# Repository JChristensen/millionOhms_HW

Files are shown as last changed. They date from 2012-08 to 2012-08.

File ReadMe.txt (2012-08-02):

Million Ohms Project Hardware
Jack Christensen
V1.2 31Jul2012

This repository contains the following for the Million Ohms project:

Assembly Instructions
Schematic
Eagle Files

This work is licensed under the Creative Commons Attribution-ShareAlike 3.0
Unported License. To view a copy of this license, visit
http://creativecommons.org/licenses/by-sa/3.0/ or send a letter to Creative
Commons, 171 Second Street, Suite 300, San Francisco, California, 94105, USA.

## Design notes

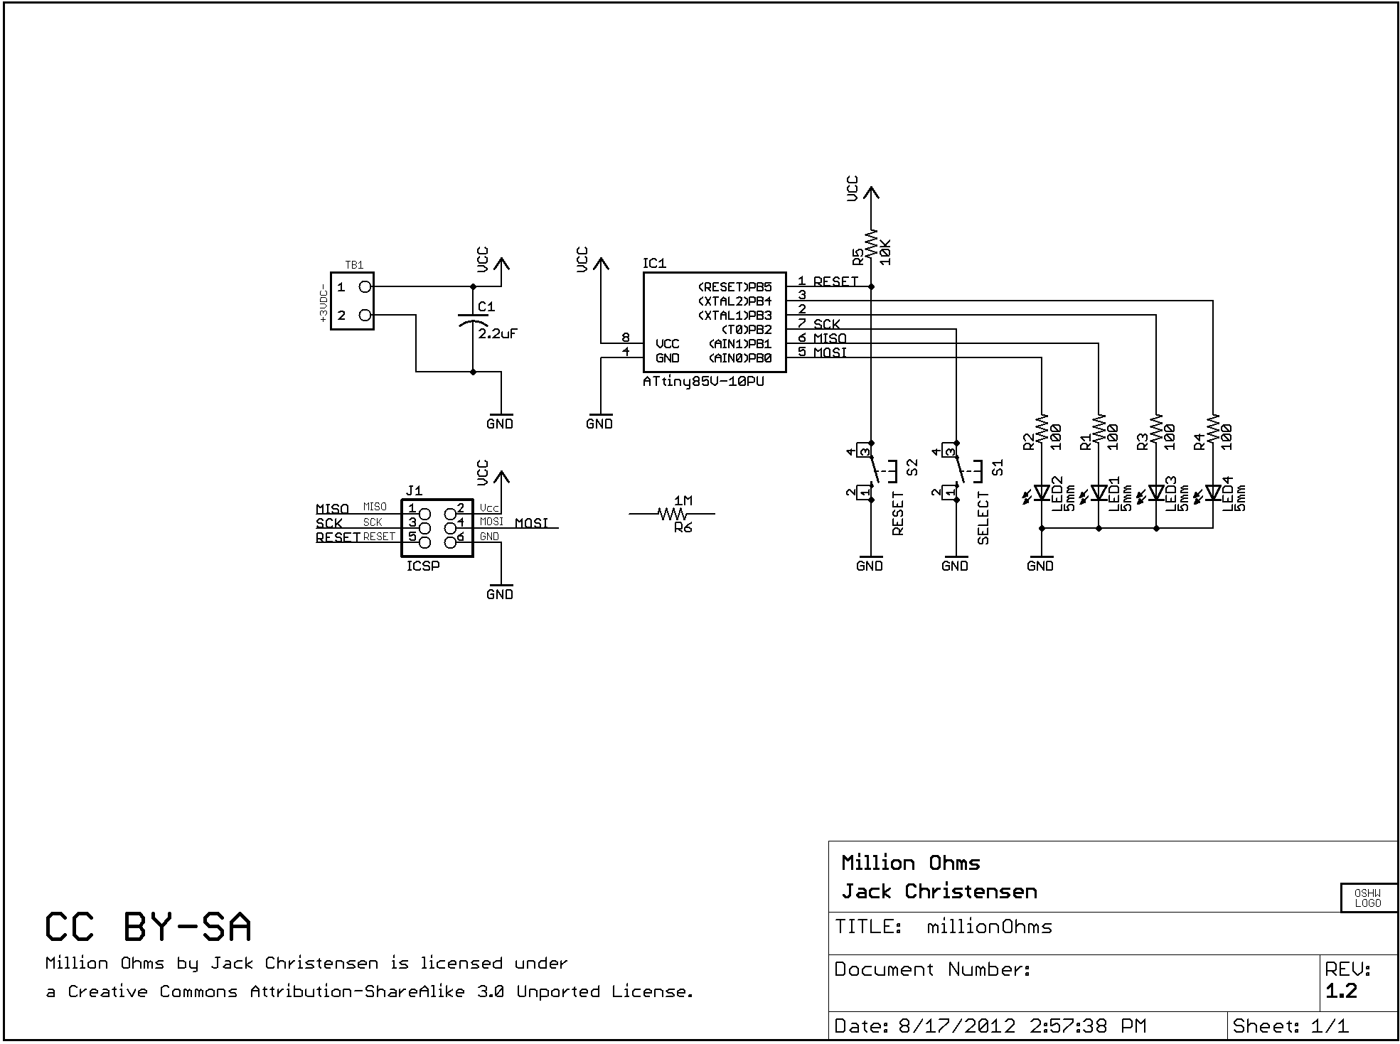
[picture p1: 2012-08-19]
schematic.png

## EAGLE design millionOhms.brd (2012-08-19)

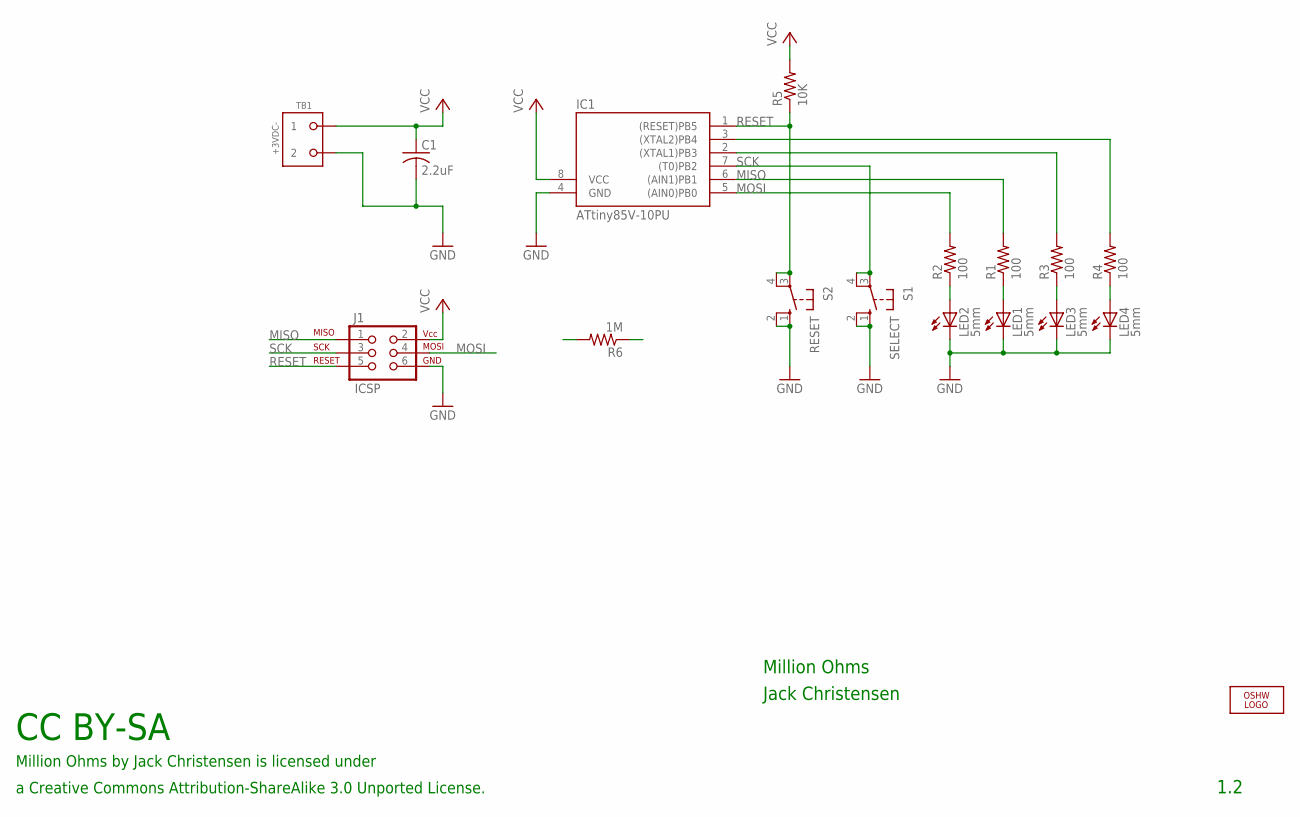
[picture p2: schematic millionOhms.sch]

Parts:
C1: 2.2uF; C025-025X050
IC1: ATtiny85V-10PU; DIL08
J1: ICSP; 2X3
LED1, LED2, LED3, LED4: 5mm; LED5MM
LOGO2: OSHW_LOGO_8MILX0150-NT; OSHW_8X150_NOTEXT
R1, R2, R3, R4: 100; 0204/6
R5: 10K; 0204/6
R6: 1M; 5616/20
S1: SELECT; B3F-10XXOCT
S2: RESET; B3F-10XXOCT
TB1: +3VDC-; OST-TB-2-3.5MM

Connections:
GND: C1.2, IC1.4 (GND), J1.6, LED1.K (C), LED2.K (C), LED3.K (C), LED4.K (C), S1.1 (S), S1.2 (S1), S2.1 (S), S2.2 (S1), TB1.P$2 (2)
MISO: IC1.6 ((AIN1)PB1), J1.1, R1.2
MOSI: IC1.5 ((AIN0)PB0), J1.4, R2.2
unnamed: LED2.A, R2.1
unnamed: LED1.A, R1.1
unnamed: LED3.A, R3.1
unnamed: LED4.A, R4.1
unnamed: IC1.2 ((XTAL1)PB3), R3.2
unnamed: IC1.3 ((XTAL2)PB4), R4.2
RESET: IC1.1 ((RESET)PB5), J1.5, R5.1, S2.3, S2.4 (P1)
SCK: IC1.7 ((T0)PB2), J1.3, S1.3, S1.4 (P1)
VCC: C1.1, IC1.8 (VCC), J1.2, R5.2, TB1.P$1 (1)

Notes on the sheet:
Million Ohms by Jack Christensen is licensed under
CC BY-SA
a Creative Commons Attribution-ShareAlike 3.0 Unported License.
Million Ohms
Jack Christensen
1.2

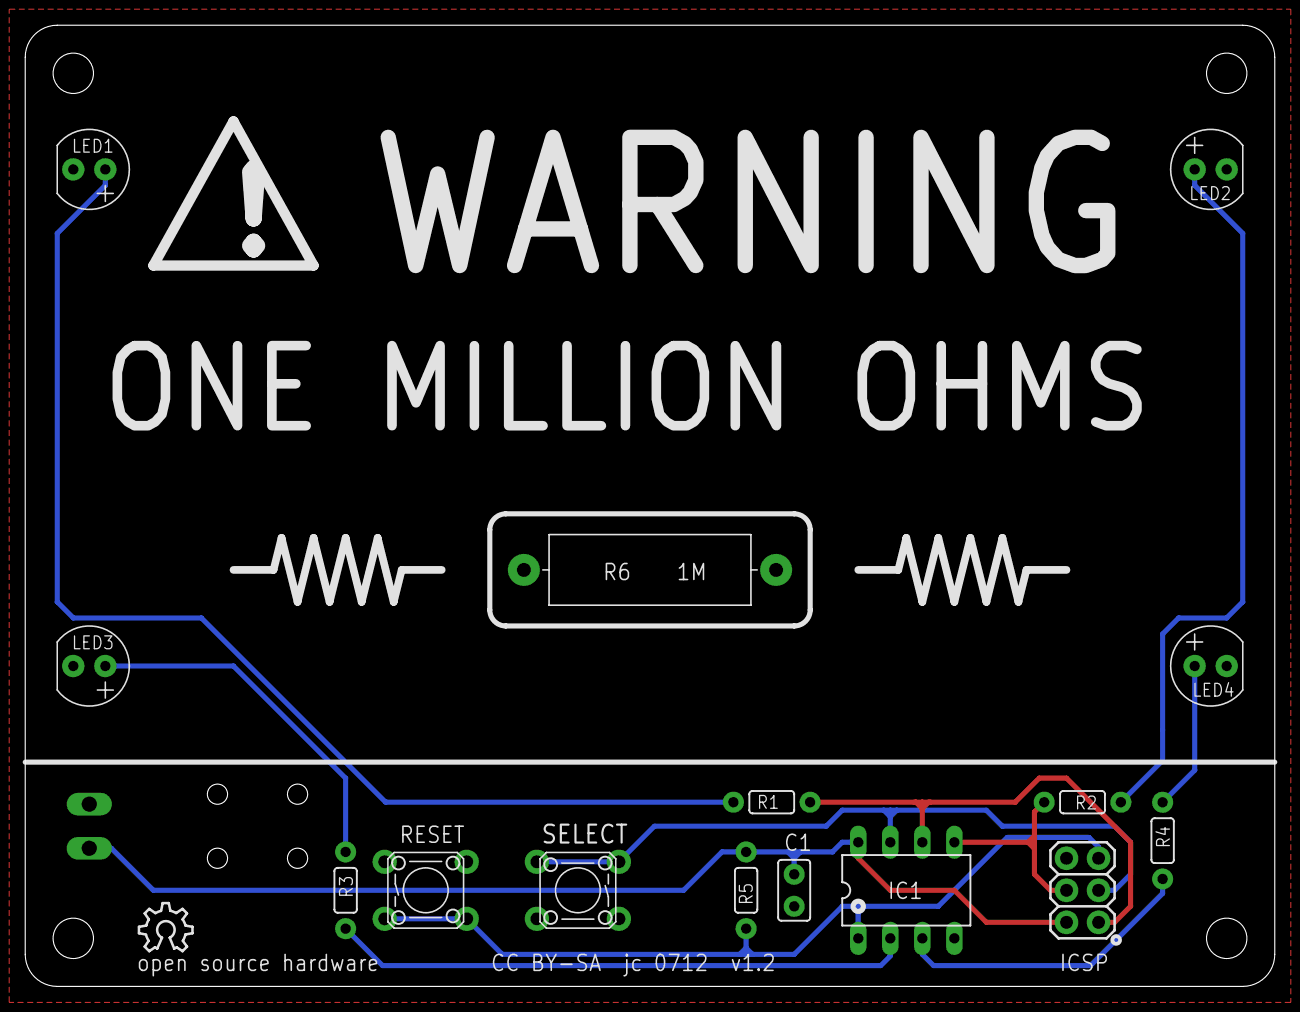
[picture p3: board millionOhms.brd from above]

Board: 2 copper layers, 99.1 x 76.2 mm, 17 parts (1 on the bottom side), 12 nets.

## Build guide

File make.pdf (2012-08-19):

## "One Million Ohms" Microcontroller Project Kit

Where to buy it: tinyurl.com/BuyMohms

Amuse your friends and confuse your enemies! Keep the uninitiated away from your workbench or desk and out of your lab!

- Great conversation piece or gag gift
- Big, scary 1,000,000 Ω resistor in the middle of the board
- Pre-programmed AVR microcontroller (ATtiny85)
- Arduino-compatible, hackable open-source hardware and software
- Can be re-programmed with an ICSP programmer, using either the Arduino (http://arduino.cc/) integrated development environment or WinAVR. (http://winavr.sourceforge.net/)

This soldering kit is an electronic version of an old joke known to physicists and engineers. Pressing the SELECT button turns the circuit on and causes the red LEDs to flash. To change the flashing speed and pattern, press SELECT again. Hold SELECT down to turn the circuit off, or it will automatically turn itself off after five minutes.

### Assembly Tips

1. Even though this is a simple kit that a beginner should be able to complete with little difficulty, these instructions are general in nature and assume that you know how to solder and can determine where to place the components on the board. If you need to learn how to solder, there are several good tutorials on the web. Check out SparkFun Electronics’ tutorial (tinyurl.com/3f4dpxj), and Adafruit Industries also has several good links (tinyurl.com/3ooo2fj).
2. Be sure to observe polarity when installing the following components. Observe the outlines on the board (also see Parts Placement on the last page of these instructions.)
a. LEDs may have a longer lead denoting positive (+) and/or a flat on the side denoting negative (-). See picture at tinyurl.com/d2bwtec
b. The microcontroller may have a notch on one end, and/or a small dot near pin 1.
c. Connect the red wire (positive) from the battery holder to the terminal block screw nearest the bottom of the board (+) and the black wire (negative) to the (-) screw. Observe polarity when installing batteries as marked on the battery holder.
3. The microcontroller is sensitive to static electricity and is shipped in conductive foam for protection. Normally a lot of fancy precautions aren’t necessary, but don’t scuff across the carpet and then touch the chip. Touch some metal object or appliance before handling the chip. Once soldered onto the board, the chip is safe.
4. As shipped from the factory, the leads on the microcontroller are spread out a bit and need to be bent in to fit into the board. One way to do this is to carefully press each side of the chip against a table top. Bend the four pins on each side just a bit so that they are parallel. See picture at tinyurl.com/9dahxr5

Where to buy it: tinyurl.com/BuyMohms

5. Double check the small resistors before soldering them. There is one 10,000 Ω (10 KΩ) resistor and four 100 Ω resistors. They only differ by one color-code band (see parts list below). If unsure, use a magnifying glass or an ohmmeter to check the values.
6. Positioning of the terminal block and battery holder is flexible depending on your intended use and installation of the board. To allow the board to stand at a slight angle on a desk, etc., put the terminal block and the battery holder on the back side of the circuit board. Use a one-inch square of double-stick foam tape to fasten the battery holder about 0.2 inch (4mm or 5mm) from the bottom of the board.
7. There are four small holes in the circuit board near the terminal block. These can be used as strain reliefs for the battery wires by threading the wires through the holes. See the pictures at tinyurl.com/MohmsPics. Where you locate the battery holder, whether you use the strain relief holes, and how long you leave the wires from the battery holder all depend on your personal preference and installation.
8. A reset button and an ICSP header are not normally required and are not included in the kit. These are left to be added by the user if desired, e.g. if they intend to reprogram the unit with an ICSP programmer.

### Parts List

C1 | 2.2uF ceramic
IC1* | Atmel microcontroller, ATtiny85V-10PU (or ATtiny45V-10PU)
ICSP | Programming header, 0.1" pitch, 2x3 (Optional, not included in kit)
LED1-4* 5mm LED
R1-4 | 100Ω, 1/8W or 1/6W, ±5% (brown, black, brown, gold)
R5 | 10KΩ, 1/8W or 1/6W, ±5% (brown, black, orange, gold)
R6 | 1MΩ, 2W, ±5% (brown, black, green, gold)
SELECT 6mm tactile button switch
RESET | 6mm tactile button switch (Optional, not included in kit)
TB1 | Terminal block, 3.5mm pitch, two position
| Battery holder, 2xAA with cover
| Double-stick foam tape
| Printed circuit board

*Observe polarity when installing.

Where to buy it: tinyurl.com/BuyMohms

### Links of Interest

Hackable open-source!
- Hardware: tinyurl.com/MohmsHW
- Software: tinyurl.com/MohmsSW

Assembly pictures: tinyurl.com/MohmsPics These instructions: tinyurl.com/MakeMohms

### Parts Placement

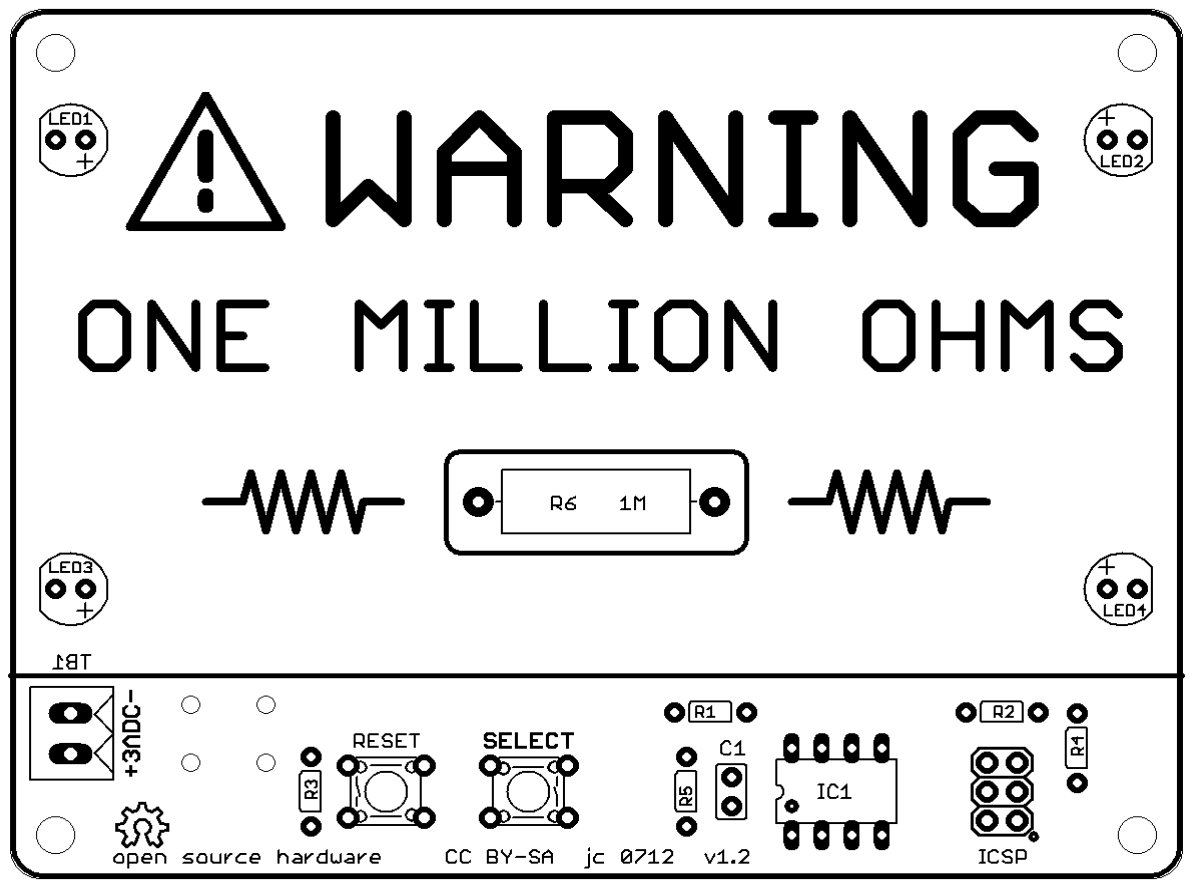
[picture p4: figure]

Jack Christensen
V1.2 Jul-2012

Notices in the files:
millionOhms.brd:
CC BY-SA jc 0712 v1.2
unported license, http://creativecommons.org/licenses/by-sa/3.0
